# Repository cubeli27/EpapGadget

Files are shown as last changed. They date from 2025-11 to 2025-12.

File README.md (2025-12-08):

# E-paper Gadget

## Overview

**EpapGadget** is a self contained solution and development platform for Epaper displays. More specifically the PCB is based on the ESP32-C3, taylored for the display [WeAct-Epaper4.2"](https://github.com/WeActStudio/WeActStudio.EpaperModule), and battery powered suitable for wall/door/monitor mounting. In this repo continuous development is done on two firmware solutions; Co-op, Solo.

<!-- To-do: Add more photos to the list -->
<p align="center"> 
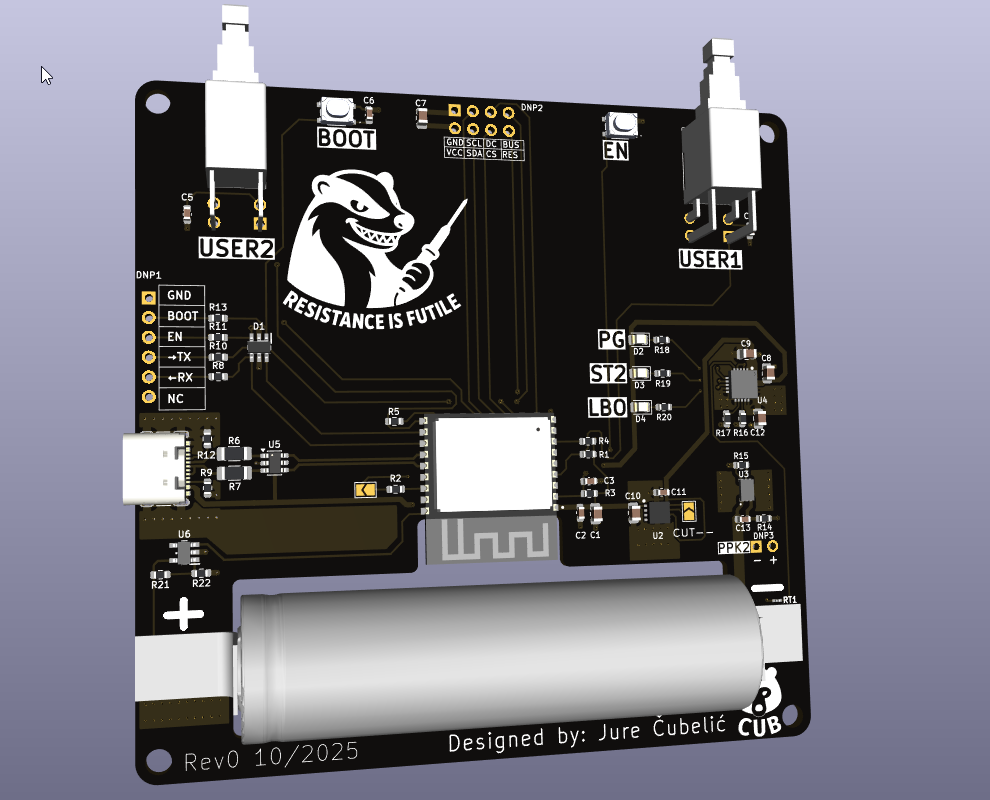
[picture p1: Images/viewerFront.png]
   
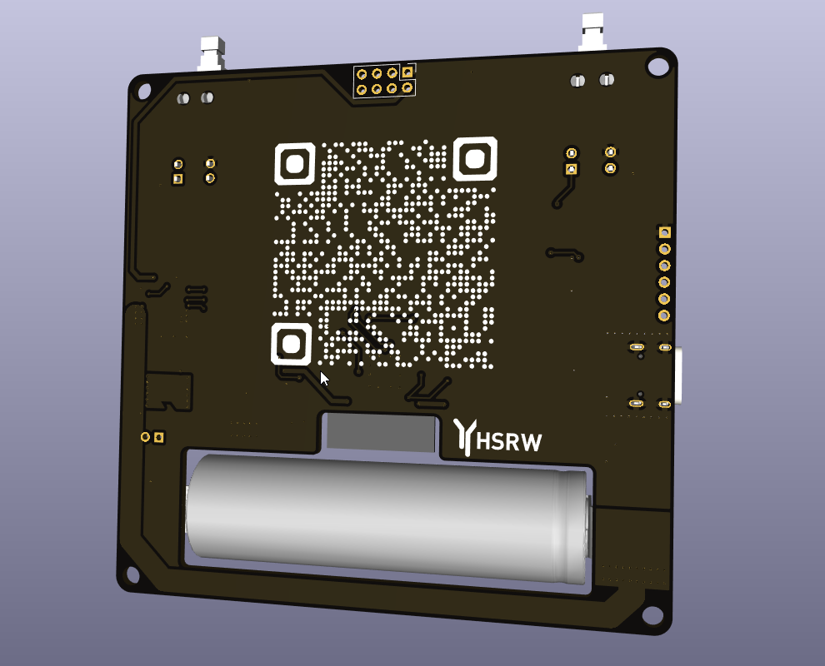
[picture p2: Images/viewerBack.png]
   
</p> 

**Key Features:**
- E-paper display
- ESP32-C3-WROOM-02
- WiFi
- USB-C for charging, programming, power
- System Load Sharing between Battery and USB-C 
- Works a month or more on a single charge (depending on the sleep cycle)
- Updated via Telegram Bot API
- Screen updates every 6s/60s/custom

---

## Project Structure

| Folder | Description | Contents |
|---|---|---|
| **ArduinoIDE_Epaper_Example** | Arduino IDE example code and instructions | .ino file |
| **CAD_files** | Contains CAD files  | Mounting parts, battery holder and clip |
| **ECAD_files** | Contains PCB files | Rev0  |
| **Images** | Report relevant snippets | Images |
| **Source_Code** | Firmware developed for this project | Co-op, Solo |

---

## Final Results

Images of project mounted on the door frame and in operation running CO-OP firmware.
<p align="center"> 
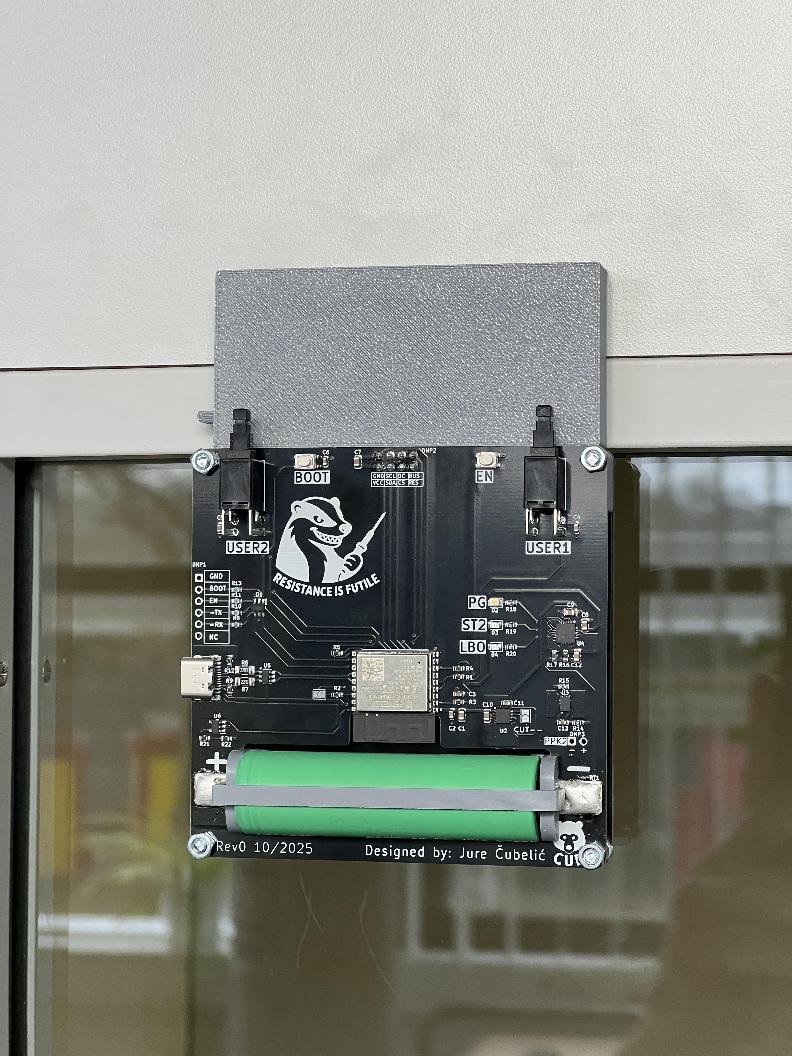
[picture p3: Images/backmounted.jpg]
   
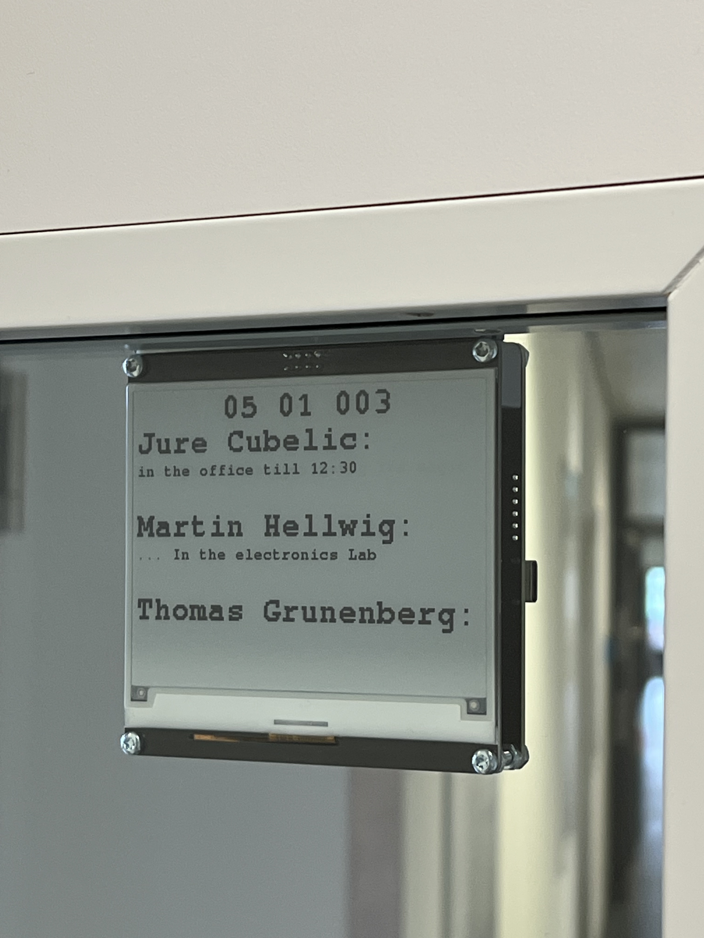
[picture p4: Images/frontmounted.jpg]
   
</p>  

---
## Firmware

Co-op: 
Designed for up to 3 people where they can send telegram messages in a groupchat that appear on the Epaper display. Depending on the location of the device, messages can be directed to a specific person or group or the broader public view. 

Example1: Suitable for mounting on office or workshop doors and leaving relevant information to anyone who comes by such as "I'll be back in 15min" or "Not here today".

Example2: Can be placed somewhere at home for example for motivation messages to you family members, loved ones, or friends such as "Have a productive day {insert name}" or "Could you please take out the trash I couldn't manage this morning".  

Solo:
Peronalised TODO list for busy/forgetfull people to unclogg the phone with endless todo lists and apps, once you randomly remember you need to do something you can send a message to your telegram bot and once you come back to your work station the **Task** that needs to be done will be displayed on your Epaper display preventing that you forget what you had in mind. 

---
## Power Consumption 
All the current measurements were conducted with the [Power profiler Kit ||](https://www.nordicsemi.com/Products/Development-hardware/Power-Profiler-Kit-2), see bellow:
<p align="center"> 
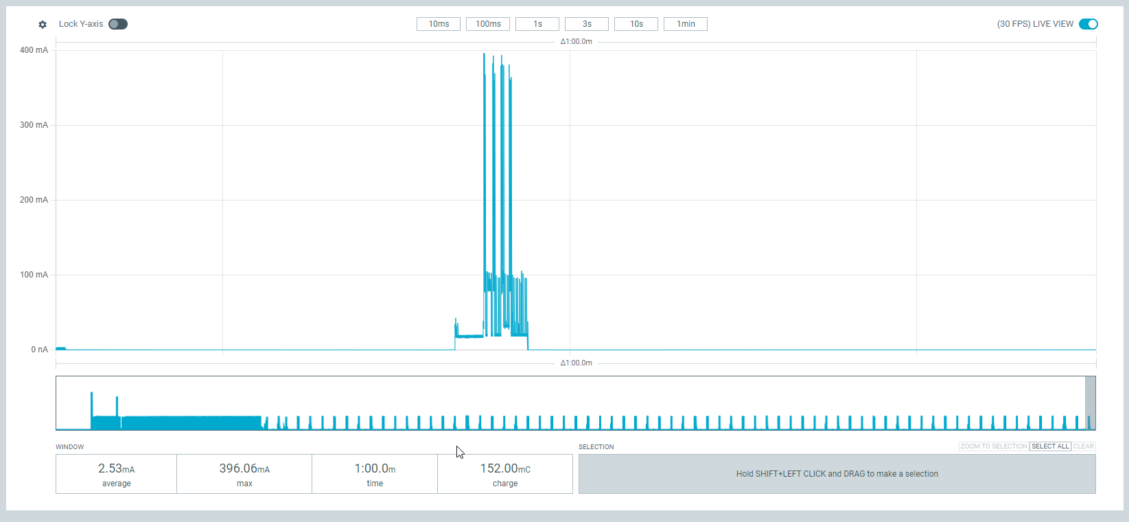
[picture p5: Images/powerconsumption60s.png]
   
</p> 

From the given measurement results it can be concluded that with the current consumption of 2.5mA on average at the 60s deep sleep cycle this gives the project a theorethical ~1000 hours of working time with the standard 2500mAh 18650 cells. Thats just under 42 days, with a generous 25% safety margin it can be said that the device requires a charge once a month. 

<p align="center"> 
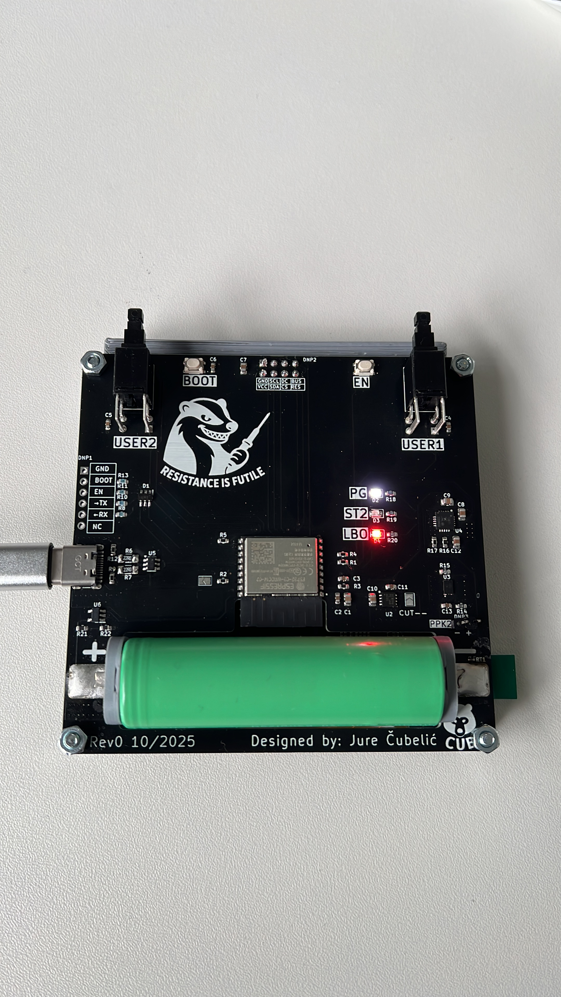
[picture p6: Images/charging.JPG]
   
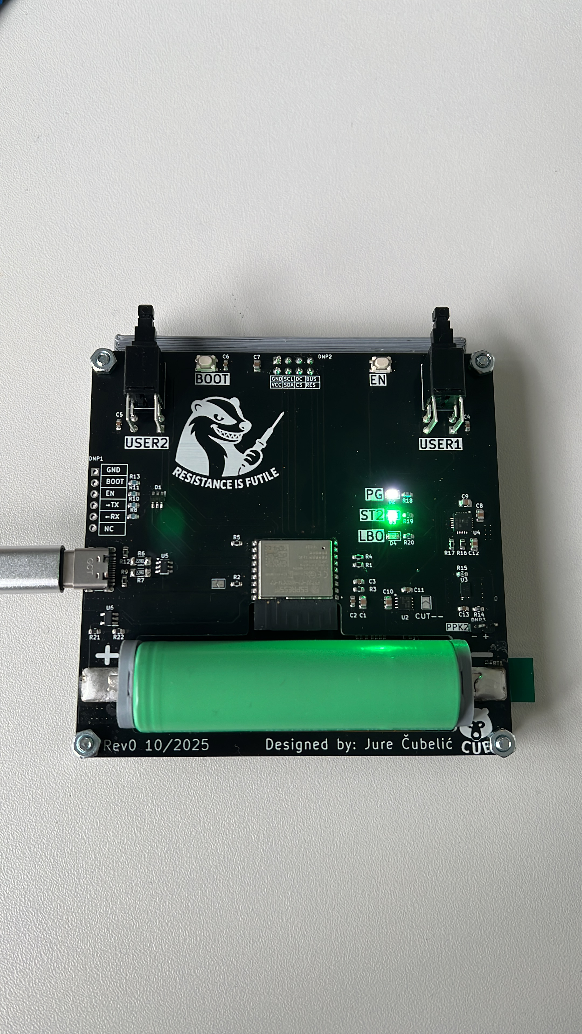
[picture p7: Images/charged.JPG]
   
</p> 

---
## Future Work
- Revision 1 intended to host the bare 4 inch epaper display instead of the module
- change LDO to boost converter to extend usable battery voltage range (currently testing cutoff)
- consolidate BOM 
- code optimisation + additional features still in progress(bat/wifi icon, user inputs, aesthetics) 
- add arduino example/test code, instructions

---
## Sponsor Acknowledgment
I extend my heartfelt gratitude to **PCBWay** for their generous support and contribution to this project.  
Their commitment to fostering innovation and learning in PCB design has been instrumental in making this project possible.  
I am very pleased with the **customer support** throughout the process and even more with the **quality of the delivered printed circuit boards.**

Sponsor Logo

**Contact Information**  
For inquiries or to learn more about PCBWay, please visit [www.pcbway.com](https://www.pcbway.com)  
or contact them directly at 📧 **service@pcbway.com**

---
## Author

Developed by **cubeli27**  
For questions or collaboration, feel free to reach out. See my contact info in the [profile repo](https://github.com/cubeli27/cubeli27).

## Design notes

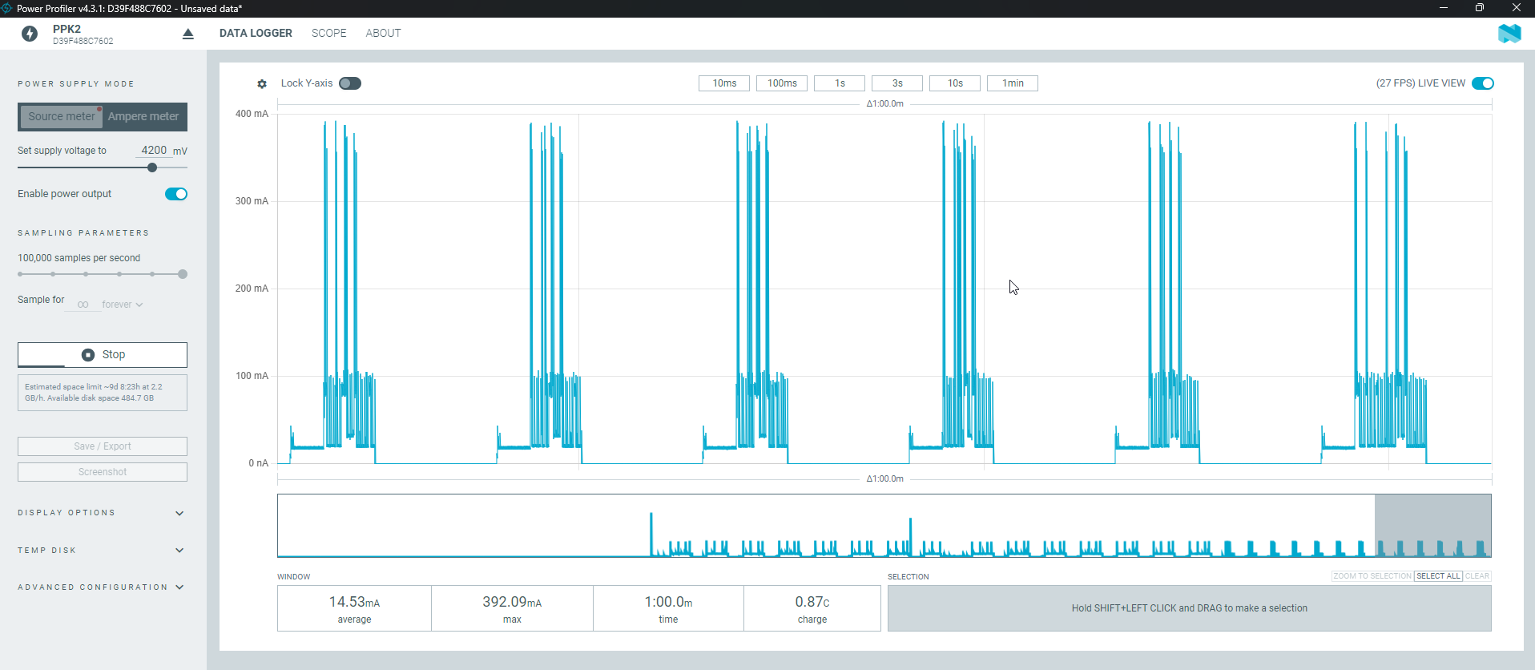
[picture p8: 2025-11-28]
Images/power_sleep6s.png

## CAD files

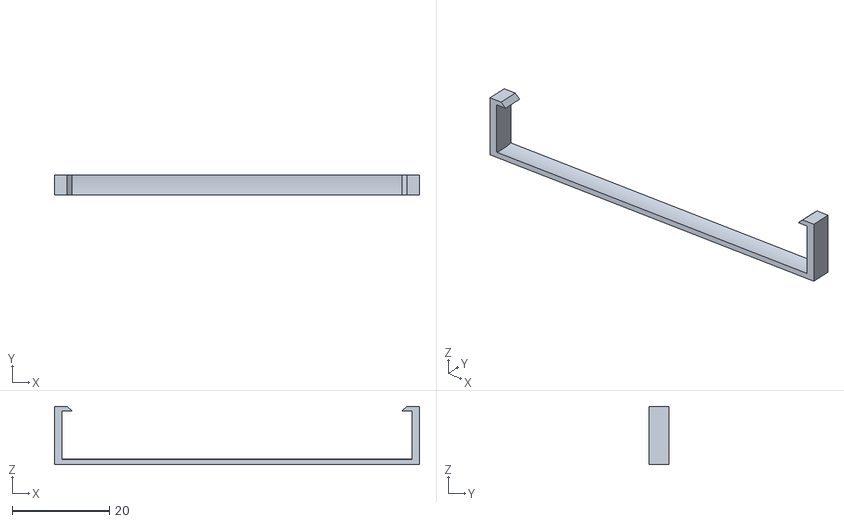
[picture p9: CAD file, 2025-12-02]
CAD_files/BatClip.stl
75.0 x 4.20 x 12.0

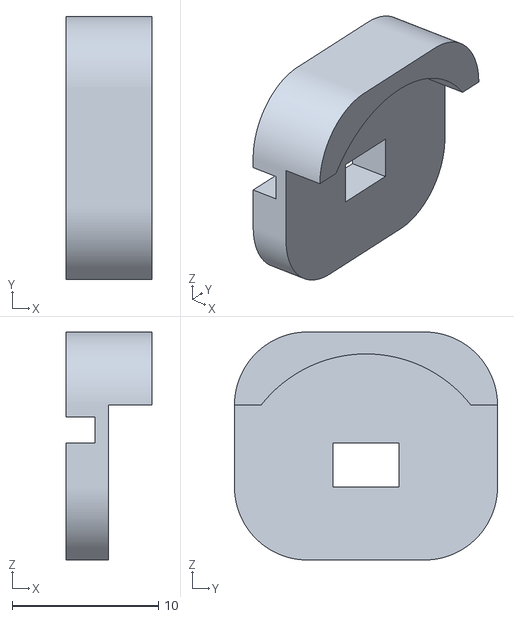
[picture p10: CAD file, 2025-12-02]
CAD_files/Batholder.stl
5.90 x 18.0 x 15.6

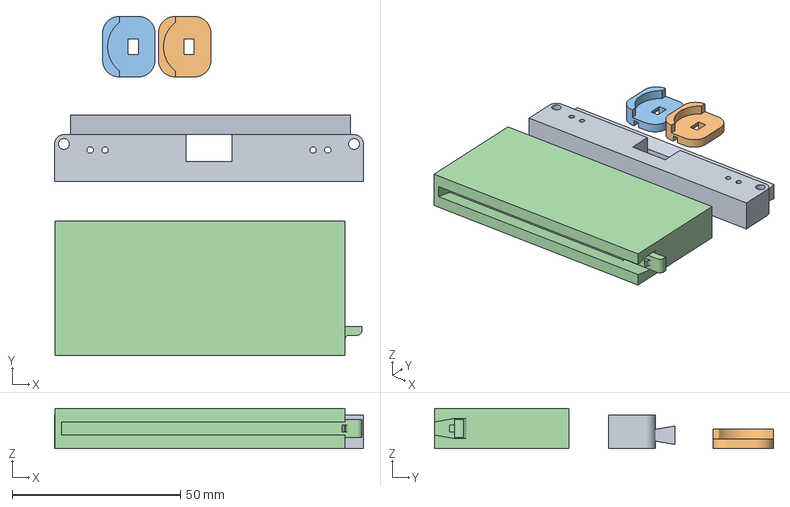
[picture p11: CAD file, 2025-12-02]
CAD_files/epap.3mf
91.8 x 100.8 x 12.0 mm
EpapAttachment.stl
Batholder.stl x 2
Mount.stl

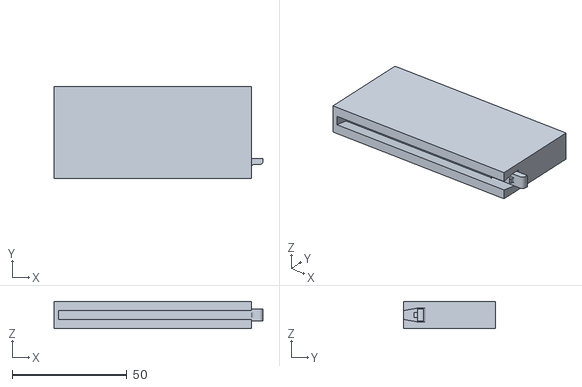
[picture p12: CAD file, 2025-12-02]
CAD_files/Mount.stl
91.2 x 40.0 x 12.0

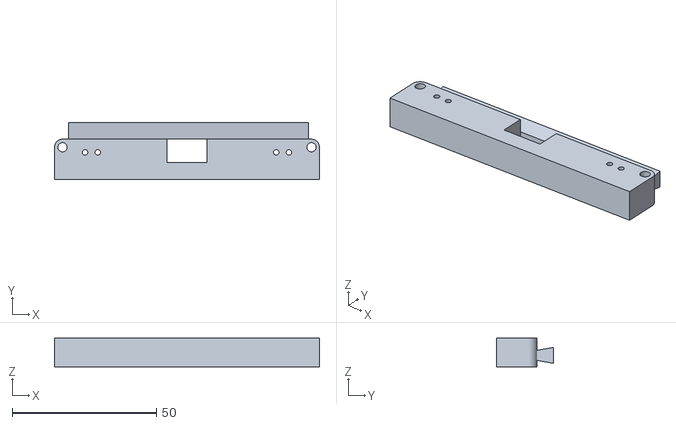
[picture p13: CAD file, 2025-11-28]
CAD_files/EpapAttachment.stl
91.8 x 19.8 x 10.0

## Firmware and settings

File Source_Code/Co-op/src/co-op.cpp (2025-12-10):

/* board: ESPC3 Dev Module
--- Pin mapping for ESP32-C3-WROOM-02---
#define CS_PIN 7 // Chip select - IO7
#define BUSY_PIN 3 // Busy - IO3
#define RES_PIN 2 // Reset - IO2
#define DC_PIN 1 // Data/Command - IO1
#define SCL_PIN 4 // SCK - IO4
#define SDA_PIN 6 // MOSI - IO6
#define USER1 (5) // button1
#define USER2 (10) // button2
*/
#include <Arduino.h>
#include <GxEPD2_BW.h>
#include <Fonts/FreeMonoBold9pt7b.h>
#include <esp_sleep.h>
#include <esp32/rtc.h>
#include <WiFi.h>
#include <private.h>
#include <HTTPClient.h>
#include <ArduinoJson.h>
#include <cstring>
#include <time.h>
#include "driver/adc.h"
#include "esp_adc_cal.h"

esp_adc_cal_characteristics_t adc_chars;
#define BATTERY_CALIB_MV -3   // manual calibration(compare with multimeter), compensate for voltage divider and ADC error

void setFrame();
void fetchTelegramMessage();
void partialUpdateTelegramMsgs();
int readBatteryMillivolts();
void outputBattery();
void goToSleep();

//DEBUGING STUFF-------------------------------------------
#define DEBUG 0 // 1= enable debug prints, 0=disable debug prints

#if DEBUG == 1
  #define DEBUG_PRINTLN(x)    Serial.println(x)
  #define DEBUG_PRINT(x)      Serial.print(x)
#else
  #define DEBUG_PRINTLN(x)
  #define DEBUG_PRINT(x)
#endif
//---------------------------------------------------------

// base class GxEPD2_GFX can be used to pass references or pointers to the display instance as parameter, uses ~1.2k more code
// enable or disable GxEPD2_GFX base class
#define ENABLE_GxEPD2_GFX 0

// ESP32-C3 CS(SS)=7,SCL(SCK)=4,SDA(MOSI)=6,BUSY=3,RES(RST)=2,DC=1
#define CS_PIN (7)
#define BUSY_PIN (3)
#define RES_PIN (2)
#define DC_PIN (1)

#define INPUT1 (5)
#define INPUT2 (10)

// 2.13'' EPD Module
//GxEPD2_BW<GxEPD2_213_BN, GxEPD2_213_BN::HEIGHT> display(GxEPD2_213_BN(/*CS=5*/ CS_PIN, /*DC=*/ DC_PIN, /*RES=*/ RES_PIN, /*BUSY=*/ BUSY_PIN)); // DEPG0213BN 122x250, SSD1680
// 4.2'' EPD Module
GxEPD2_BW<GxEPD2_420_GDEY042T81, GxEPD2_420_GDEY042T81::HEIGHT> display(GxEPD2_420_GDEY042T81(/*CS=5*/ CS_PIN, /*DC=*/ DC_PIN, /*RES=*/ RES_PIN, /*BUSY=*/ BUSY_PIN)); // 400x300, SSD1683


//------------------------------------------------------------------------------------------------------------------------------------------------------------------------------------------
// RTC_DATA_ATTR for retaining data during sleep
RTC_DATA_ATTR bool FrameSet = 0; //flag to know if frame was set already
RTC_DATA_ATTR int counter = 0; //just for testing increments on each wakeup
RTC_DATA_ATTR uint16_t User1_X ;
RTC_DATA_ATTR uint16_t User1_Y ;
RTC_DATA_ATTR uint16_t User2_X ;
RTC_DATA_ATTR uint16_t User2_Y ;
RTC_DATA_ATTR uint16_t User3_X ;
RTC_DATA_ATTR uint16_t User3_Y ;
RTC_DATA_ATTR uint16_t pad = 15; //padding for text boxes
RTC_DATA_ATTR char telegramMessage1[110] = "No Msg"; //110 chars enough for 3 rows at font size 1   
RTC_DATA_ATTR char telegramMessage2[110] = "No Msg";
RTC_DATA_ATTR char telegramMessage3[110] = "No Msg";
RTC_DATA_ATTR long lastUpdateId = 0;   //super necessary to keep track of last read message offset
//------------------------------------------------------------------------------------------------------------------------------------------------------------------------------------------
void setup()
{
  Serial.begin(115200);
  DEBUG_PRINTLN("Setup/ woke up");
  //timezone
  setenv("TZ", "CET-1CEST,M3.5.0/02:00:00,M10.5.0/03:00:00", 1);
  tzset();
  //eink pins
  pinMode(CS_PIN, OUTPUT);
  pinMode(DC_PIN, OUTPUT);
  pinMode(RES_PIN, OUTPUT);
  pinMode(BUSY_PIN,OUTPUT);
  //buttons
  pinMode(INPUT1, INPUT);
  pinMode(INPUT2, INPUT);
  // Configure ADC1 channel 0 = GPIO0
  adc1_config_width(ADC_WIDTH_BIT_12);
  adc1_config_channel_atten(ADC1_CHANNEL_0, ADC_ATTEN_11db);
  // Characterize ADC with default Vref = 1100mV
  esp_adc_cal_characterize(
      ADC_UNIT_1,
      ADC_ATTEN_11db,
      ADC_WIDTH_BIT_12,
      1100,
      &adc_chars
  );

  if (!FrameSet) {
    display.init(115200,true,50,false);
    delay(1500);//giving it some extra time seems to help
    setFrame();
    FrameSet = 1;
    DEBUG_PRINTLN("First boot, setting frame");
  } 
  else {
    DEBUG_PRINTLN("Frame set -> partial update");
  }
  display.init(115200,false,50,false); //partial update mode
  delay(1500);//giving it some extra time seems to help
  fetchTelegramMessage();
  partialUpdateTelegramMsgs();
  readBatteryMillivolts();
  outputBattery();
  goToSleep();
}


void setFrame() //first display update after init
{
  display.setRotation(0); // 0 rotation for 4inch from connector down 
  display.setFont(&FreeMonoBold9pt7b);
  display.setTextColor(GxEPD_BLACK);
  display.setTextSize(2);
  //x,y of top left corner of the text bounding box, height and width of text in pixels
  int16_t tbx0, tby0; uint16_t tbw0, tbh0;
  int16_t tbx1, tby1; uint16_t tbw1, tbh1;
  int16_t tbx2, tby2; uint16_t tbw2, tbh2;
  int16_t tbx3, tby3; uint16_t tbw3, tbh3;
  display.getTextBounds(title, 0, 0, &tbx0, &tby0, &tbw0, &tbh0);
  display.getTextBounds(user1, 0, 0, &tbx1, &tby1, &tbw1, &tbh1);
  display.getTextBounds(user2, 0, 0, &tbx2, &tby2, &tbw2, &tbh2);
  display.getTextBounds(user3, 0, 0, &tbx3, &tby3, &tbw3, &tbh3);
  // PRINTING TITLE HORIZONTALLY CENTERED AND USERS BELOW TITLE EVENLY SPACED
  uint16_t x = 0; uint16_t y = 0;
  display.setFullWindow();
  display.firstPage();
  do
  {
    display.fillScreen(GxEPD_WHITE);
    //print title
    display.setCursor((display.width() - tbw0) / 2, y + tbh0);
    display.print(title);
    //print user1
    display.setCursor(x, y-tby1+tbh0+pad);
    display.print(user1);
    User1_X = tbw1;
    User1_Y = y - tby1 + tbh0 + pad;
    //print user2
    display.setCursor(x, y-tby2+tbh0+pad+(display.height()-tbh0-pad)/3);
    display.print(user2);
    User2_X = tbw2;
    User2_Y = y - tby2 + tbh0 + pad + (display.height()-tbh0-pad)/3;
    //print user3
    display.setCursor(x, y-tby3+tbh0+pad+(display.height()-tbh0-pad)/3*2);
    display.print(user3);
    User3_X = tbw3;
    User3_Y = y - tby3 + tbh0 + pad + (display.height()-tbh0-pad)/3*2;
  }
  while (display.nextPage());
  DEBUG_PRINTLN("tbx0: "+String(tbx0)+", tby0: "+String(tby0)+", tbw0: "+String(tbw0)+", tbh0: "+String(tbh0));
  DEBUG_PRINTLN("tbx1: "+String(tbx1)+", tby1: "+String(tby1)+", tbw1: "+String(tbw1)+", tbh1: "+String(tbh1));
  DEBUG_PRINTLN("tbx2: "+String(tbx2)+", tby2: "+String(tby2)+", tbw2: "+String(tbw2)+", tbh2: "+String(tbh2));
  DEBUG_PRINTLN("tbx3: "+String(tbx3)+", tby3: "+String(tby3)+", tbw3: "+String(tbw3)+", tbh3: "+String(tbh3));
}

bool user1Updated = true;
bool user2Updated = true;
bool user3Updated = true;

void fetchTelegramMessage() 
{
  if (WiFi.status() != WL_CONNECTED) { //connect to WiFi if not connected
    WiFi.begin(WIFI_SSID, WIFI_PASSWORD);
    DEBUG_PRINTLN("Connecting to : " + String(WIFI_SSID));
    int attempts = 0;
    while (WiFi.status() != WL_CONNECTED && attempts < 20) {
      delay(500);
      attempts++;
    }
  }

  if (WiFi.status() == WL_CONNECTED) {
    DEBUG_PRINTLN("Connected WiFi, checking Telegram, lastUpdateId: " + String(lastUpdateId));
    HTTPClient http;
    String url = "https://api.telegram.org/bot" + String(TELEGRAM_BOT_TOKEN) + "/getUpdates?offset=" + String(lastUpdateId + 1) + "&limit=1";   
    http.begin(url);
    int httpCode = http.GET();

    if (httpCode == HTTP_CODE_OK) {
      String payload = http.getString();
      DynamicJsonDocument doc(4096);
      deserializeJson(doc, payload);

      if (doc["result"].size() > 0) {
        DEBUG_PRINTLN("New message received");
        JsonObject message = doc["result"][doc["result"].size() - 1]["message"];

        const char* text = message["text"];
        const char* username = message["from"]["username"];  // sender username
        lastUpdateId = doc["result"][doc["result"].size() - 1]["update_id"];

        if (text && strlen(text) > 0) {
            if (username && strcmp(username, USER1_USERNAME) == 0) {
                strncpy(telegramMessage1, text, sizeof(telegramMessage1));
                telegramMessage1[sizeof(telegramMessage1)-1] = '\0';
                user1Updated = true;
                DEBUG_PRINTLN("User1 message: " + String(telegramMessage1));
            } 
            else if (username && strcmp(username, USER2_USERNAME) == 0) {
                strncpy(telegramMessage2, text, sizeof(telegramMessage2));
                telegramMessage2[sizeof(telegramMessage2)-1] = '\0';
                user2Updated = true;
                DEBUG_PRINTLN("User2 message: " + String(telegramMessage2));
            } 
            else if (username && strcmp(username, USER3_USERNAME) == 0) {
                strncpy(telegramMessage3, text, sizeof(telegramMessage3));
                telegramMessage3[sizeof(telegramMessage3)-1] = '\0';
                user3Updated = true; 
                DEBUG_PRINTLN("User3 message: " + String(telegramMessage3));
            }
            else {
                DEBUG_PRINTLN("Message from unknown user: " + String(username));
            }
        }
      }
    }
    http.end();
  }
}


void partialUpdateTelegramMsgs()
{
  const uint16_t msgBoxX = 0;
  const uint16_t msgBoxW = display.width(); // width of the message area
  const uint16_t msgBoxH = (display.height()-22)/3-40;  // 40 good number:)

  if (user1Updated){
    //for testing
    // user2Updated = true;
    // user3Updated = true;
    // strcpy(telegramMessage2, telegramMessage1);
    // strcpy(telegramMessage3, telegramMessage1);
    //end testing
    DEBUG_PRINTLN("Partial update USER1 Telegram message"); 
    user1Updated = false; // clear the flag
    const uint16_t msgBoxY = User1_Y+10; //10 to give enough padding to not cut the g in Hellwig
    display.setPartialWindow(msgBoxX, msgBoxY, msgBoxW, msgBoxH);
    display.firstPage();
    do {
        display.fillRect(msgBoxX, msgBoxY, msgBoxW, msgBoxH, GxEPD_WHITE);
        display.setFont(&FreeMonoBold9pt7b);
        display.setTextColor(GxEPD_BLACK);
        display.setTextSize(1);
        display.setCursor(msgBoxX, msgBoxY + 15);   // baseline offset
        display.print(telegramMessage1);
      } while (display.nextPage());
  }
  if (user2Updated){
  DEBUG_PRINTLN("Partial update USER2 Telegram message");
  user2Updated = false; // clear the flag
  const uint16_t msgBoxY = User2_Y + 10; //10 to give enough padding to not cut the g in Hellwig
  
  display.setPartialWindow(msgBoxX, msgBoxY, msgBoxW, msgBoxH);
  display.firstPage();
  do {
      display.fillRect(msgBoxX, msgBoxY, msgBoxW, msgBoxH, GxEPD_WHITE);
      display.setFont(&FreeMonoBold9pt7b);
      display.setTextColor(GxEPD_BLACK);
      display.setTextSize(1);
      display.setCursor(msgBoxX, msgBoxY + 15);   // baseline offset
      display.print(telegramMessage2);
    } while (display.nextPage());
  }
  if (user3Updated){
  DEBUG_PRINTLN("Partial update USER3 Telegram message");
  user3Updated = false; // clear the flag
  const uint16_t msgBoxY = User3_Y + 10; //10 to give enough padding to not cut the g in Hellwig

  display.setPartialWindow(msgBoxX, msgBoxY, msgBoxW, msgBoxH);
  display.firstPage();
  do {
      display.fillRect(msgBoxX, msgBoxY, msgBoxW, msgBoxH, GxEPD_WHITE);
      display.setFont(&FreeMonoBold9pt7b);
      display.setTextColor(GxEPD_BLACK);
      display.setTextSize(1);
      display.setCursor(msgBoxX, msgBoxY + 15);   // baseline offset
      display.print(telegramMessage3);
    } while (display.nextPage());
  }
}

int readBatteryMillivolts()
{
    const int samples = 6;
    uint32_t raw_accum = 0;

    for (int i = 0; i < samples; i++) {
        raw_accum += adc1_get_raw(ADC1_CHANNEL_0);
    }

    uint32_t raw = raw_accum / samples;
    uint32_t adc_pin_mV = esp_adc_cal_raw_to_voltage(raw, &adc_chars);
    uint32_t battery_mV = adc_pin_mV * 2;   // calculate for voltage divider
    battery_mV += BATTERY_CALIB_MV;         // manual offset

    return battery_mV;
}

void outputBattery() {
    int mv = readBatteryMillivolts();
    DEBUG_PRINTLN("Battery mV: " + String(mv));
    char batteryStr[20] = "";
    snprintf(batteryStr, sizeof(batteryStr), "%s%dmV", batteryStr, mv);

    const uint16_t battX = display.width() - 30 - 6 * strlen(batteryStr);
    const uint16_t battY = 12;

    display.setPartialWindow(battX, 0, 20*20, 20);
    display.firstPage();
    do {
        display.fillRect(battX, 0, display.width() - battX, 16, GxEPD_WHITE);
        display.setFont(&FreeMonoBold9pt7b);
        display.setTextColor(GxEPD_BLACK);
        display.setTextSize(1);
        display.setCursor(battX, battY);
        display.print(batteryStr);
    } while (display.nextPage());
}


void goToSleep()
{
  DEBUG_PRINTLN("Sleep counter at "+String(counter)+", going to sleep for 60s");
  counter++;
  delay(1000); //give some time to see the message before sleeping
  display.hibernate();  //put display to hibernate to save power
  esp_sleep_enable_timer_wakeup(60*1000000); // x times 1million microseconds = x*1s = xs
  esp_deep_sleep_start();
}


void loop() 
{
  //youll do nüthing
}

/*TODO LIST:
-user inputs handling
-text wrapping for telegram messages, truncation for too long messages
*/

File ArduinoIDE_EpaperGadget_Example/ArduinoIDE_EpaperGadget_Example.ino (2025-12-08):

/*
STEPS: 
BOARDS MANAGER: install "esp32" or "Arduino ESP32 Boards"
LIBRARY MANAGER: install GxEPD2 by Jean-Marc Zingg
Tools:
-Select Board: "ESPC3 Dev Module"
-Select Port: "COM{something}"
-USB CDC On Boot: Enabled
|
|
--- Pin mapping for ESP32-C3-WROOM-02---
#define CS_PIN 7 // Chip select - IO7
#define BUSY_PIN 3 // Busy - IO3
#define RES_PIN 2 // Reset - IO2
#define DC_PIN 1 // Data/Command - IO1
#define SCL_PIN 4 // SCK - IO4
#define SDA_PIN 6 // MOSI - IO6
#define USER1 (5) // Button1 - IO5
#define USER2 (10) // Button2 -IO10
*/

#include <GxEPD2_BW.h>
#include <Fonts/FreeMonoBold9pt7b.h>
// base class GxEPD2_GFX can be used to pass references or pointers to the display instance as parameter, uses ~1.2k more code
// enable or disable GxEPD2_GFX base class
#define ENABLE_GxEPD2_GFX 0

// ESP32-C3 CS(SS)=7,SCL(SCK)=4,SDA(MOSI)=6,BUSY=3,RES(RST)=2,DC=1
#define CS_PIN (7)
#define BUSY_PIN (3)
#define RES_PIN (2)
#define DC_PIN (1)
#define INPUT1 (5)
#define INPUT2 (10)

// 4.2'' EPD Module
GxEPD2_BW<GxEPD2_420_GDEY042T81, GxEPD2_420_GDEY042T81::HEIGHT> display(GxEPD2_420_GDEY042T81(/*CS=5*/ CS_PIN, /*DC=*/ DC_PIN, /*RES=*/ RES_PIN, /*BUSY=*/ BUSY_PIN)); // 400x300, SSD1683

int counter = 0;  
void setup()
{
  Serial.begin(115200);
  Serial.println("setup");
  display.init(115200,true,50,false);
  delay(1000);
  setFrame();
  display.init(115200,false,50,false);
}

const char Line1[] = "Hello";
const char Line2[] = "World";
int16_t y2;
void setFrame()
{
  display.setRotation(0);
  display.setFont(&FreeMonoBold9pt7b);
  display.setTextColor(GxEPD_BLACK);
  int16_t tbx, tby; uint16_t tbw, tbh;
  display.setFullWindow();
  display.firstPage();
  do {
    display.fillScreen(GxEPD_WHITE);
    //Line1
    display.setTextSize(1);
    display.getTextBounds(Line1, 0, 0, &tbx, &tby, &tbw, &tbh);
    int16_t x1 = (display.width() - tbw)/2 - tbx;
    int16_t y1 = display.height()/2 - tbh;
    display.setCursor(x1, y1);
    display.print(Line1);
    //Line 2
    display.setTextSize(2);
    display.getTextBounds(Line2, 0, 0, &tbx, &tby, &tbw, &tbh);
    int16_t x2 = (display.width() - tbw)/2 - tbx;
    y2 = y1 + tbh + 10;
    display.setCursor(x2, y2);
    display.print(Line2);
  } while (display.nextPage());
}

char counterChar[20];
void partialUpdateCounter()
{
  sprintf(counterChar,"%d",counter);
  display.setTextSize(1);
  int16_t ptbx, ptby; uint16_t ptbw, ptbh;
  display.getTextBounds(counterChar, 0, 0, &ptbx, &ptby, &ptbw, &ptbh); 
  uint16_t PartialUpdateX = (display.width() - ptbw)/2 - ptbx;
  uint16_t PartialUpdateY = y2 + 20;
  uint16_t PartialUpdateW = ptbw + 10;
  uint16_t PartialUpdateH = ptbh + 10;
  display.setPartialWindow(PartialUpdateX,PartialUpdateY,PartialUpdateW,PartialUpdateH);
  display.firstPage();
  do{
    display.fillRect(PartialUpdateX,PartialUpdateY,PartialUpdateW,PartialUpdateH,GxEPD_WHITE);
    display.setCursor(PartialUpdateX,PartialUpdateY - ptby);
    display.print(counterChar);
  }
  while(display.nextPage());
  Serial.println("Counter:"+String(counter));
  counter += 1;
}


void loop() 
{
  Serial.println("loop");
  partialUpdateCounter();
  delay(5000);//
}

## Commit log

2025-10-25 Can Differentiate Telegram Users,Partial Update Display with those New Messages while keeping previous Frame
2025-11-27 fix project .gitignore,single user minor imprv
    [singleuser.cpp]
2025-11-28 cad models and images
    [Batholder.stl, EpapAttachment.stl, Mount.stl]
2025-12-01 add:temp file,fix:title space, msgBoxH 3rows,g lower half user letters cut
    [Mount.stl]
2025-12-01 tolerances, release knob
    [Batholder.stl, Mount.stl]
2025-12-02 coop debug line, solo usb cdc,images,cad tolerances fixed,battery clip
    [BatClip.stl, Batholder.stl, Mount.stl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]
2025-12-04 accurately read bat voltage, do something with it
2025-12-08 example arduino code
2025-12-10 battery monitoring, default user msgs
